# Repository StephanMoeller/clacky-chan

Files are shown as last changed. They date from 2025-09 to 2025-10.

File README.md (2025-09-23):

# Clacky Chan 
Clacky Chan is a custom made prototype split keyboard for testing out communication using trrs cables between the halves.

It consists of:

- rp2040 pro micro
- pcb's for each half and wire attached thumb keys as I want the thumbs to be tented just slightly on relation to the finger area.
- No diodes. (it toke 20 mins of soldering for each side. It is not the last time I will try a diode-free design)

Its running my own firmware, zigmkay, which can be found here: https://github.com/StephanMoeller/zigmkay

# Black version - Unibody case
7f63db8b-d6e0-4c39-9a91-76ac389d0bd9
2fe62f42-b4df-402e-ac64-a8a9cb1a0f7f
d4c0fe6e-fffc-4eb9-a765-44190064d145
e9f355bb-30e8-4752-bb39-aa15e23ebeb3
0af01adf-e6e9-4c1b-97dd-531818d74c7d
bbfe21ab-32e2-4533-92b4-2e22920a8e99
90a544af-5f98-4dbb-adc4-b786cee89c0b

# Yellow version - Unibody case
0e690a9f-9a9f-48c4-8cef-8b80c9a6f156
65da4e0c-8134-4725-a974-a8907a2f9301

# Yelow version - Split case
71d9d91a-8ce8-4dc4-b1a9-bd24813d666e
ad2c0e29-a139-48bc-9a63-2b7b12f0825a
b09ff933-2e11-4308-b0d9-10f68c65feef
bc37182f-509c-406f-89c6-056639b44986
bf89299e-6e8e-4636-850b-74c77fa247b9
e1264128-50f4-48ad-9a02-e3029bf71215
ff60f66d-b6b9-4421-adec-dca49aa49fca
8c7d04c5-575d-4bbf-8a1f-15eb03bb9990 (1)
dbb364ab-9d85-4f8b-a48c-94f8f26aa15f

PCB gerber files for production can be found in clackychan/production/clackychan.zig

Following picture uses wiring, eg. GPIO 6 is used as the single col and all the row pins can be determined as well. The thumb keys are wired to the GPIO 6 and then I choose GPIO 10 in the corner as the row.


Ongoing OnShape repo with the tenting: https://cad.onshape.com/documents/76ee9714ee23fe3d9d1e73a4/w/b73638d5ae9d33482cab6d43/e/1ea8409974f0fb535c971db1

All my boards:

https://github.com/StephanMoeller/clacky-chan  
https://github.com/StephanMoeller/mike-typeson  
https://github.com/StephanMoeller/skinnypete32  
https://github.com/StephanMoeller/wilson26

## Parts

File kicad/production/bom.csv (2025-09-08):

Designator | Footprint | Quantity | Value | LCSC Part #
S1, S10, S11, S12, S13, S14, S15, S2, S3, S4, S6, S7, S8, S9 | Kailh_socket_MX_reversible | 14 | Keyswitch
U1 | RP2040_Pro_Micro | 1 | RP2040_Pro_Micro
U2, U3 | TRRS_PJ-320A | 2 | TRRS

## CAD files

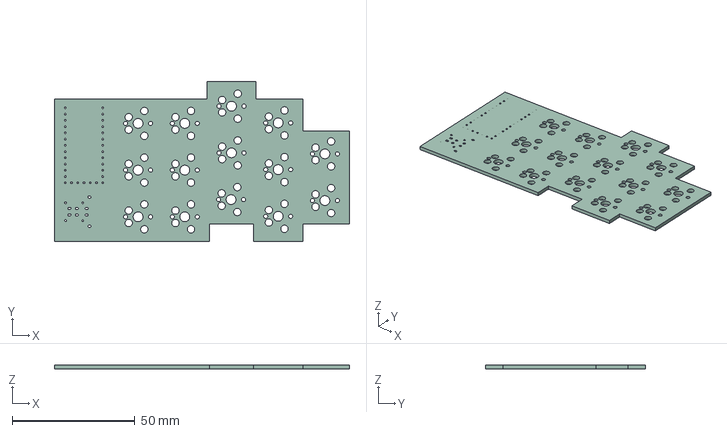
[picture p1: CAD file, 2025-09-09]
kicad/clackychan.step
120.0 x 65.0 x 1.51 mm

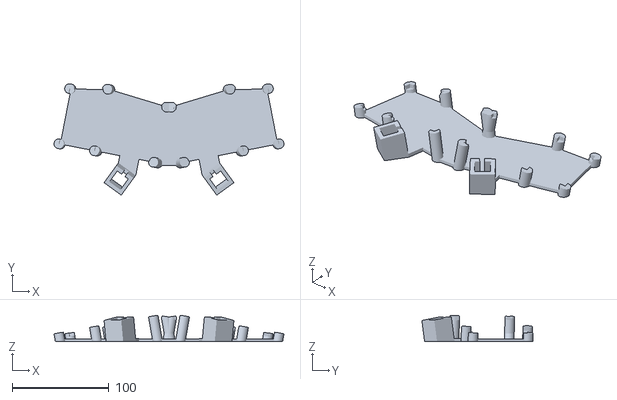
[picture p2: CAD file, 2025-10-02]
stl/ClackyChan - unibody case.stl
237.6 x 115.0 x 27.4

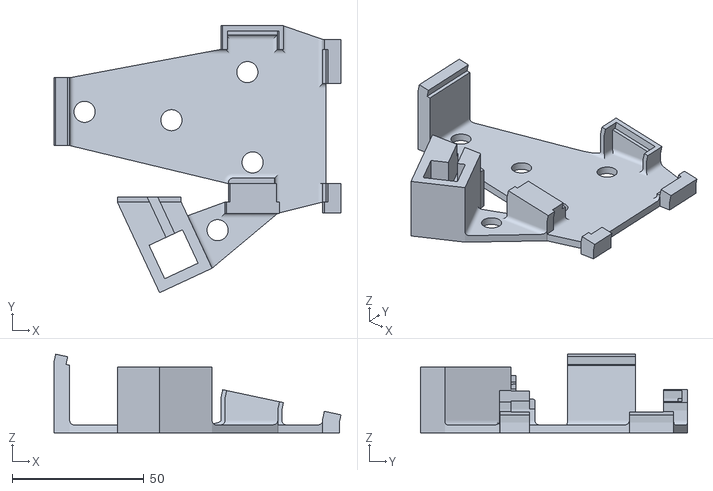
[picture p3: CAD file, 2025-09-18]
stl/Clacky Chan tenting v6.stl
109.0 x 101.6 x 29.9

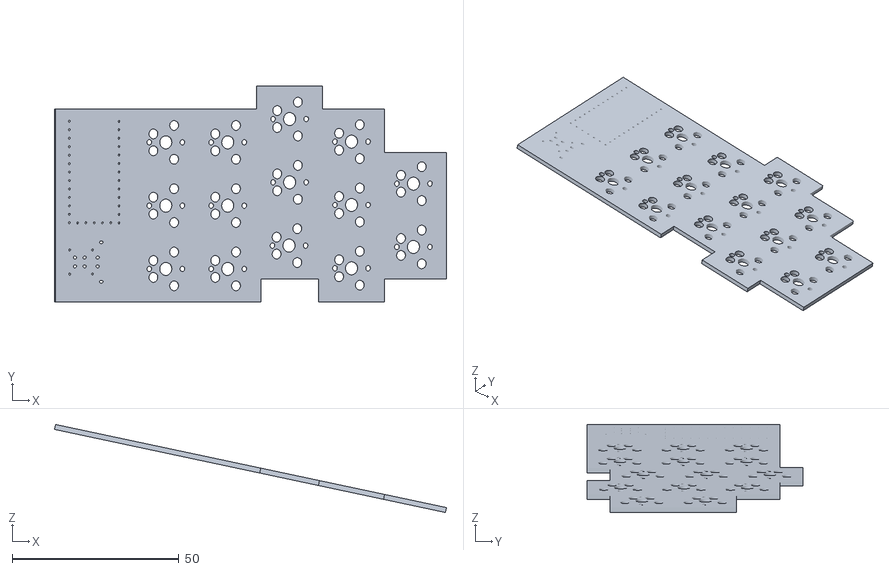
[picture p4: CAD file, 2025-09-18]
stl/ClackyChan pcb as stl for modelling new tentings.stl
117.7 x 65.0 x 26.4

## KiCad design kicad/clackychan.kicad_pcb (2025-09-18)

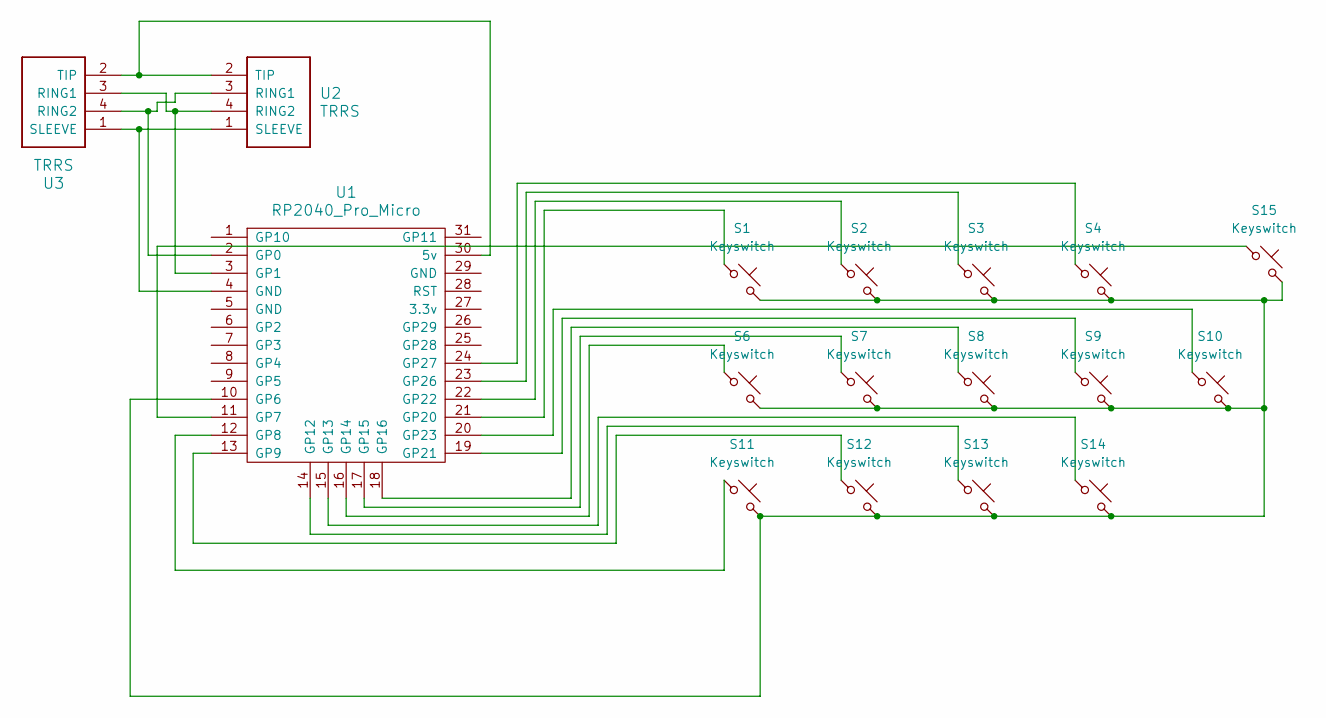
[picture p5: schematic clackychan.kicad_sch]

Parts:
S1, S2, S3, S4, S6, S7, S8, S9, S10, S11, S12, S13, S14, S15: Keyswitch; Kailh_socket_MX_reversible
U1: RP2040_Pro_Micro
U2, U3: TRRS; TRRS_PJ-320A

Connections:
unnamed: U1.30 (5v), U2.2 (TIP), U3.2 (TIP)
unnamed: U1.2 (GP0), U2.3 (RING1), U3.4 (RING2)
unnamed: U1.3 (GP1), U2.4 (RING2), U3.3 (RING1)
unnamed: S1.2, S2.2, S3.2, S4.2, S6.2, S7.2, S8.2, S9.2, S10.2, S11.2, S12.2, S13.2, S14.2, S15.2, U1.10 (GP6)
unnamed: S15.1, U1.11 (GP7)
unnamed: S11.1, U1.12 (GP8)
unnamed: S12.1, U1.13 (GP9)
unnamed: S13.1, U1.14 (GP12)
unnamed: S14.1, U1.15 (GP13)
unnamed: S6.1, U1.16 (GP14)
unnamed: S7.1, U1.17 (GP15)
unnamed: S8.1, U1.18 (GP16)
unnamed: S1.1, U1.21 (GP20)
unnamed: S9.1, U1.19 (GP21)
unnamed: S2.1, U1.22 (GP22)
unnamed: S10.1, U1.20 (GP23)
unnamed: S3.1, U1.23 (GP26)
unnamed: S4.1, U1.24 (GP27)
unnamed: U1.4 (GND), U2.1 (SLEEVE), U3.1 (SLEEVE)

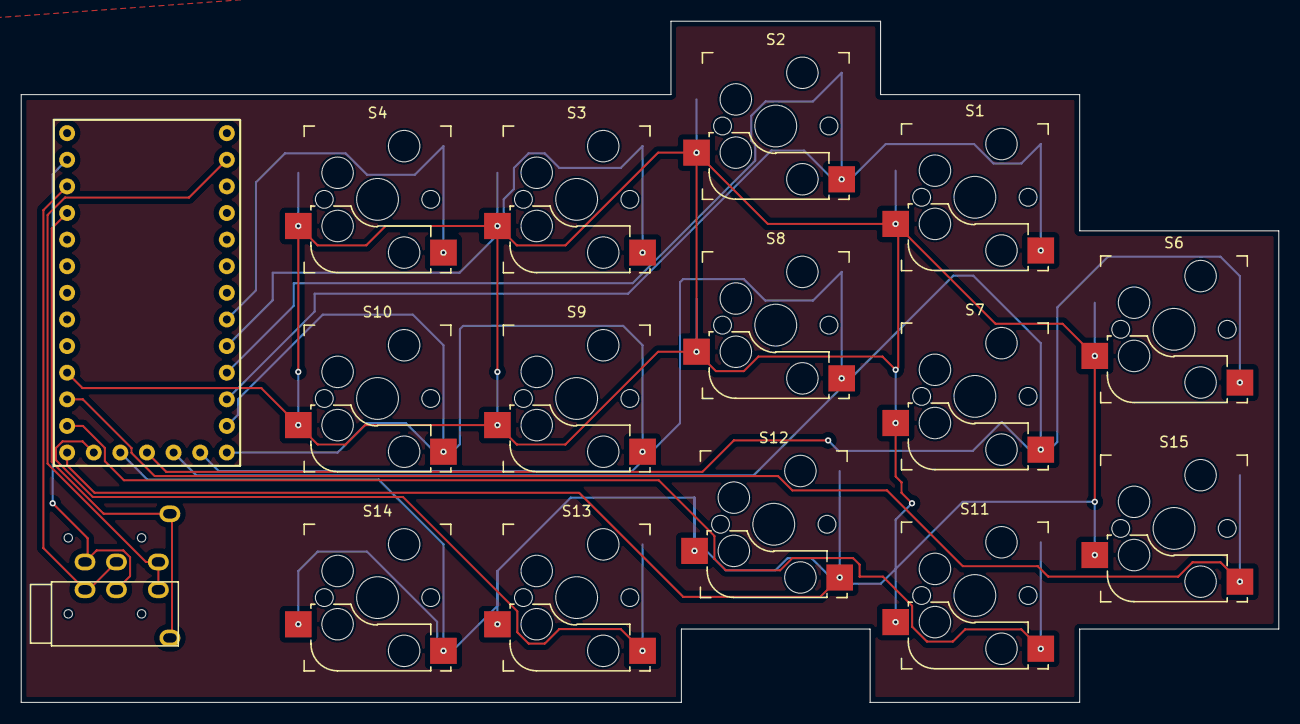
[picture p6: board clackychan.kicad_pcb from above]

Board: 2 copper layers, 120.0 x 65.0 mm, 17 parts (1 on the bottom side), 19 nets.

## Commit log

2025-09-08 init files
    [clackychan.kicad_pcb, clackychan.kicad_sch]
2025-09-08 ordered gerber files added to git
    [bom.csv, designators.csv, positions.csv]
2025-09-09 added a step file
    [clackychan.step]
2025-09-18 added stl
    [Clacky Chan tenting v6.stl, ClackyChan pcb as stl for modelling new tentings.stl, clackychan.kicad_pcb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]
2025-09-18 renamed to kicad folder
    [bom.csv, clackychan.kicad_pcb, clackychan.kicad_sch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]
2025-09-22 added unibody stl
    [clacky_chan_unibody_case.stl]
2025-10-02 replaced wrong unibody case stl with right one
    [ClackyChan - unibody case.stl, clacky_chan_unibody_case.stl]
